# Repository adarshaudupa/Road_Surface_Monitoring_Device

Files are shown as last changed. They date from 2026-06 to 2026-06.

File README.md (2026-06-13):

<div align="center">

<!--
  ╔══════════════════════════════════════════════════════════════╗
  ║  IMAGE 1 — BANNER                                            ║
  ║  File: docs/images/banner.png                                ║
  ║  Suggested size: 1280 × 400 px                               ║
  ║  Use Canva / Figma to make a dark-themed banner with the     ║
  ║  project name, a road icon, and your institution name.       ║
  ╚══════════════════════════════════════════════════════════════╝
-->
Banner

#  Road Condition Monitoring System

**A vehicle-mounted embedded sensing platform that autonomously detects road anomalies,
geo-tags them with real-time GPS, and streams telemetry to a live web dashboard.**

<br>










[]()
[]()

</div>

---

##  Table of Contents

- [Overview](#-overview)
- [Live Dashboard Preview](#-live-dashboard-preview)
- [System Architecture](#-system-architecture)
- [Hardware Platform](#-hardware-platform)
- [Sensor Subsystems](#-sensor-subsystems)
- [Firmware Architecture](#-firmware-architecture)
- [Communication Protocol](#-communication-protocol)
- [Road Event Classification](#-road-event-classification)
- [Web Dashboard & Backend](#-web-dashboard--backend)
- [Repository Structure](#-repository-structure)
- [Getting Started](#-getting-started)
- [Team](#-team)
- [Concepts Demonstrated](#-concepts-demonstrated)
- [Future Improvements](#-future-improvements)
- [Current Status](#-current-status)

---

##  Overview

The **Road Condition Monitoring System** is a complete end-to-end embedded IoT platform that mounts on an RC vehicle and autonomously surveys road surface quality in real time.

The STM32F446RE microcontroller fuses data from an **IMU**, **ultrasonic rangefinder**, and **GPS receiver** to detect and geo-tag road anomalies — potholes and rough patches. Classified events are forwarded over UART to an **ESP32-S3 Wi-Fi gateway**, which uploads them to a **Python backend** for live visualization on a Leaflet.js map dashboard.

<br>

| | Capability |
|:---:|:---|
|  | **Multi-sensor fusion** — IMU shock detection cross-validated with ultrasonic surface profiling |
|  | **GPS geo-tagging** — NMEA GPGGA parsing with interrupt-driven ring-buffer architecture |
|  | **Inter-MCU telemetry** — Structured ASCII packet protocol over STM32 ↔ ESP32 UART link |
|  | **Cloud uplink** — HTTP POST pipeline from ESP32 to Python REST API |
|  | **Live dashboard** — Color-coded map markers with per-event shock & distance metrics |
|  | **Vehicle integration** — 3D-printed sensor mounts on a custom RC chassis |

---

##  Live Dashboard Preview

<!--
  ╔══════════════════════════════════════════════════════════════╗
  ║  IMAGE 2 — DASHBOARD SCREENSHOT                             ║
  ║  File: docs/images/dashboard.png                            ║
  ║  Suggested size: 1280 × 720 px                              ║
  ║  Take a full-page screenshot of the running dashboard with   ║
  ║  some events already plotted on the map.                     ║
  ╚══════════════════════════════════════════════════════════════╝
-->
Dashboard

> Real-time Leaflet.js map showing pothole (🔴) and rough road (🟠) events, with per-event shock magnitude, GPS coordinates, and timestamp.

---

##  System Architecture

<!--
  ╔══════════════════════════════════════════════════════════════╗
  ║  IMAGE 3 — SYSTEM ARCHITECTURE DIAGRAM                      ║
  ║  File: docs/images/architecture.png                         ║
  ║  Suggested size: 1400 × 600 px                              ║
  ║  Use draw.io / Excalidraw to recreate the ASCII diagram      ║
  ║  below as a clean block diagram with icons for each node.    ║
  ╚══════════════════════════════════════════════════════════════╝
-->
Architecture Diagram

```
  ┌──────────────┐  I²C    ┌───────────────────────────────────────────────────┐
  │  LSM6DS3 IMU │───────► │                                                   │
  └──────────────┘         │                                                   │  UART    ┌───────────┐  Wi-Fi   ┌────────────────┐
                           │            STM32F446RE                            │────────► │  ESP32-S3 │─────────►│ Backend Server │
  ┌──────────────┐  TIM5   │                                                   │          └───────────┘          └───────┬────────┘
  │   HC-SR04    │───────► │  • Sensor acquisition & fusion                    │                                         │
  └──────────────┘         │  • Event classification (pothole / rough road)    │                                         ▼
                           │  • GPS stream parsing (NMEA GPGGA)                │                                 ┌────────────────┐
  ┌──────────────┐  UART   │  • Telemetry packet generation                    │                                 │ Web Dashboard  │
  │   NEO-6M GPS │───────► │                                                   │                                 │  (Leaflet.js)  │
  └──────────────┘         └───────────────────────────────────────────────────┘                                 └────────────────┘
```

Data flows from raw sensor readings all the way to a browser-rendered map in under a second.

---

##  Hardware Platform

<!--
  ╔══════════════════════════════════════════════════════════════╗
  ║  IMAGE 4 — HARDWARE / RC CAR PHOTO                           ║
  ║  File: docs/images/hardware.png                              ║
  ║  Suggested size: 1200 × 800 px                               ║
  ║  A well-lit photo of the RC car with components labelled.    ║
  ║  Use Canva or GIMP to add callout labels over the photo.     ║
  ╚══════════════════════════════════════════════════════════════╝
-->
Hardware Platform

### Processing Nodes

| Component | Role |
|---|---|
| **STM32F446RE** | Primary sensing & processing node — sensor drivers, event classification, telemetry generation |
| **ESP32-S3** | Communication gateway — Wi-Fi HTTP uplink + BLE-based RC vehicle control |

### Sensors & Peripherals

| Device | Interface | Function |
|---|---|---|
| **LSM6DS3** | I²C | 6-axis IMU — accelerometer for shock detection |
| **HC-SR04** | TIM5 Input Capture | Ultrasonic rangefinder — road surface profiling |
| **NEO-6M** | UART | GPS receiver — position, altitude & time |
| **TB6612FNG** | GPIO / PWM | Dual motor driver — RC vehicle drive control |

### Communication Interfaces

| Link | Nodes | Protocol |
|---|---|---|
| I²C | STM32 ↔ LSM6DS3 | Register-level IMU configuration & data read |
| UART1 | STM32 ↔ NEO-6M | NMEA 0183 GPS stream (interrupt-driven) |
| UART2 | STM32 ↔ ESP32 | Structured ASCII telemetry packets |
| Wi-Fi | ESP32 ↔ Backend | HTTP POST (JSON telemetry) |
| BLE | Phone ↔ ESP32 | RC vehicle real-time control |

<!--
  ╔══════════════════════════════════════════════════════════════╗
  ║  IMAGE 5 — WIRING / PINOUT DIAGRAM                           ║
  ║  File: docs/images/wiring.png                                ║
  ║  Suggested size: 1200 × 900 px                               ║
  ║  Use Fritzing or draw.io to draw the wiring between the      ║
  ║  STM32, ESP32, sensors, and motor driver.                    ║
  ╚══════════════════════════════════════════════════════════════╝
-->
Wiring Diagram

---

##  Sensor Subsystems

###  LSM6DS3 — IMU Shock Detection

The accelerometer continuously monitors vehicle dynamics. A **low-pass gravity estimation** filter runs every sample to cleanly isolate vertical shock from static gravity:

```
Raw Accelerometer Output (x, y, z)
            │
            ▼  exponential low-pass  (α = 0.1)
    Gravity Vector Estimate  [gx, gy, gz]
            │
            ▼  vector subtraction
    Dynamic Acceleration  [ax, ay, az]
            │
            ▼  dot product with gravity unit vector
    Vertical Shock Magnitude  (g-units)
            │
            ▼  threshold comparison
    Road Event Trigger  ──►  Pothole / Rough Road
```

<!--
  ╔══════════════════════════════════════════════════════════════╗
  ║  IMAGE 6 — IMU SIGNAL WAVEFORM                               ║
  ║  File: docs/images/imu-signal.png                            ║
  ║  Suggested size: 1200 × 500 px                               ║
  ║  Use Arduino Serial Plotter or Matplotlib to plot the raw    ║
  ║  vs filtered IMU signal with a pothole event highlighted.    ║
  ╚══════════════════════════════════════════════════════════════╝
-->
IMU Signal Plot

**Implemented:** I²C init & WHO_AM_I validation · ODR & full-scale configuration · gravity estimation · low-pass filtering · vertical shock extraction · real-time interrupt processing

---

###  HC-SR04 — Ultrasonic Road Surface Measurement

TIM5 hardware input capture measures the echo pulse duration to calculate chassis-to-road distance with microsecond precision:

```
STM32 GPIO Trigger ──► 10 μs pulse
                               │
                               ▼
                        HC-SR04 emits ultrasonic burst
                               │
                               ▼
                         Echo Pin HIGH
                               │  ◄─── TIM5 Capture (rising edge)
                               ▼
                         Echo Pin LOW
                               │  ◄─── TIM5 Capture (falling edge)
                               │
                               ▼
                    Δt  =  t_fall − t_rise
                               │
                               ▼
                    Distance  =  (Δt × 343 m/s) / 2
```

**Implemented:** TIM5 input capture · rising & falling edge detection · hardware-timed pulse width measurement · non-blocking interrupt-driven acquisition

---

###  NEO-6M — GPS Telemetry

The GPS module streams **NMEA 0183** sentences continuously. The firmware implements a **ring-buffer producer–consumer** architecture to parse GPS data without ever blocking the main control loop:

```
UART3 RX Interrupt  ──►  Ring Buffer  (producer — ISR context)
                                │
                                ▼
                       Main Loop polls (consumer)
                                │
                                ▼
                     NMEA Sentence Reconstruction
                                │
                                ▼
                          GPGGA Parser
                                │
                                ▼
              ┌─────────────────┼──────────────────┐
              ▼                 ▼                  ▼
          UTC Time          Lat / Lon           Altitude
         Fix Quality     Satellite Count
```

<!--
  ╔══════════════════════════════════════════════════════════════╗
  ║  IMAGE 7 — GPS MAP TRACK                                     ║
  ║  File: docs/images/gps-track.png                             ║
  ║  Suggested size: 1200 × 700 px                               ║
  ║  Screenshot of the dashboard after a full test run with      ║
  ║  a visible GPS track of the vehicle route plotted on the map ║
  ╚══════════════════════════════════════════════════════════════╝
-->
GPS Track

**Implemented:** UART interrupt handling · circular ring buffer · stream-based NMEA reconstruction · GPGGA sentence parsing · UTC time, lat/lon, altitude, fix quality, satellite count

---

##  Firmware Architecture

The repository ships **two STM32 firmware variants** (HAL-based and bare-metal) alongside the ESP32 gateway sketch.

### `firmware-stm32-hal/` — Primary HAL-based Firmware

```
main.c                 ← System init, sensor loop, event classification, packet dispatch
  ├── LSM6DS3.c / .h   ← I²C IMU driver — init, read, gravity filter, shock extraction
  ├── HC_SR04.c / .h   ← TIM5 input-capture ultrasonic driver
  ├── NEO_6M.c  / .h   ← Interrupt-driven GPS UART + ring buffer + GPGGA parser
  └── ESP32.c   / .h   ← UART telemetry framing & transmission to ESP32
```

### `firmware-stm32-baremetal/` — Register-Level Implementation

```
main.c                   ← Bare-metal system init and application loop
  ├── lsm6ds3.c / .h     ← Direct register-level IMU driver (no HAL)
  ├── hc-sr04.c / .h     ← Register-level TIM5 driver
  ├── NEO_6M.c  / .h     ← Bare-metal UART + ring buffer
  └── esp32_comms.c / .h ← Low-level UART telemetry TX
```

> The bare-metal variant is provided as an educational reference demonstrating the same functionality at the register level, without relying on the STM32 HAL abstraction layer.

### `firmware-esp32/road_surface_monitor.ino` — Wi-Fi Gateway

```
road_surface_monitor.ino
  ├── STM32 UART reception & packet parsing
  ├── Dynamic baseline tracking for ultrasonic depth calculation
  ├── Wi-Fi connection management with status logging
  ├── HTTP POST telemetry upload to backend API
  └── BLE UART service for real-time RC vehicle control
```

---

##  Communication Protocol

The STM32 generates structured **ASCII telemetry packets** over UART. Two event types are defined:

| Event | Packet Format |
|---|---|
| **Rough Road** | `R,<shock_g>,<latitude>,<longitude>,<utc_timestamp>` |
| **Pothole** | `P,<shock_g>,<distance_cm>,<latitude>,<longitude>,<utc_timestamp>` |

**Example packets:**
```
R,1.82,12.971598,77.594562,134502.00
P,2.47,18.30,12.971598,77.594562,134512.00
```

The ESP32 parses these, enriches with `device_id`, and HTTP POSTs to the backend:

```http
POST /api/ingest HTTP/1.1
Host: 10.x.x.x:8000
Content-Type: application/json

{
  "device_id":  "esp32-car-01",
  "event":      "pothole",
  "shock":       2.47,
  "distance":   18.30,
  "lat":        12.971598,
  "lon":        77.594562,
  "timestamp":  "134512.00"
}
```

---

##  Web Dashboard & Backend

<!--
  ╔══════════════════════════════════════════════════════════════╗
  ║  IMAGE 8 — DASHBOARD DETAIL / GIF                            ║
  ║  File: docs/images/dashboard-detail.gif  (or .png)           ║
  ║  Suggested size: 1280 × 720 px                               ║
  ║  Record a short screen capture (GIF via ScreenToGif /        ║
  ║  Kap) showing a new event appearing live on the map.         ║
  ╚══════════════════════════════════════════════════════════════╝
-->
Dashboard Detail

The Python backend (`server.py`) exposes a minimal REST API:

| Endpoint | Method | Description |
|---|---|---|
| `/api/ingest` | `POST` | Receive & store telemetry from ESP32 |
| `/api/events` | `GET` | Retrieve all logged road events |
| `/` | `GET` | Serve the web dashboard |

The frontend (`index.html` + `app.js`) renders all events on an interactive **Leaflet.js** map with color-coded markers and per-event metric cards:

| Marker | Event Type |
|---|---|
| 🔴 **Red** | Pothole — high-severity surface deviation (IMU + ultrasonic confirmed) |
| 🟠 **Orange** | Rough Road — vibration-based surface anomaly (IMU only) |

**Stack:** Python · Leaflet.js · Vanilla JS · CSS Custom Properties · Groq AI integration

---

## 📂 Repository Structure

```
road-condition-monitoring-system/
│
├── firmware-stm32-hal/              ← Primary STM32 firmware (STM32CubeIDE / HAL)
│   ├── Core/
│   │   ├── Src/                     ← main.c, LSM6DS3.c, HC_SR04.c, NEO_6M.c, ESP32.c
│   │   └── Inc/                     ← Header files for all modules
│   └── Drivers/                     ← CMSIS + ST HAL drivers (auto-generated)
│
├── firmware-stm32-baremetal/        ← Register-level reference implementation
│   ├── Core/
│   │   ├── Src/                     ← main.c, lsm6ds3.c, hc-sr04.c, NEO_6M.c, esp32_comms.c
│   │   └── Inc/
│   └── Drivers/
│
├── firmware-esp32/
│   └── road_surface_monitor.ino     ← ESP32 Wi-Fi gateway + BLE RC control
│
├── web-dashboard/
│   ├── server.py                    ← Python backend REST API
│   ├── app.js                       ← Frontend map logic & live event rendering
│   ├── index.html                   ← Dashboard UI shell
│   ├── styles.css                   ← Dark-theme stylesheet
│   └── .env.example                 ← Environment variable template
│
├── model-design/
│   └── Front Leg.stl                ← 3D-printable sensor mount (FDM-ready)
│
└── docs/
    └── images/                      ← ← ← Put all your README images here
        ├── banner.png
        ├── dashboard.png
        ├── dashboard-detail.gif
        ├── architecture.png
        ├── hardware.png
        ├── wiring.png
        ├── imu-signal.png
        └── gps-track.png
```

---

##  Getting Started

### Prerequisites

- [STM32CubeIDE](https://www.st.com/en/development-tools/stm32cubeide.html) — for STM32 firmware
- [Arduino IDE](https://www.arduino.cc/en/software) with [ESP32 board support](https://docs.espressif.com/projects/arduino-esp32/en/latest/installing.html)
- Python 3.9+ — for the backend server
- ST-Link V2/V3 debugger — for flashing the STM32

---

### 1 · Flash the STM32

```bash
# In STM32CubeIDE:
File → Import → General → Existing Projects into Workspace

# Choose one of:
#   firmware-stm32-hal/          ← recommended (HAL-based)
#   firmware-stm32-baremetal/    ← advanced (register-level)

# Build (Ctrl+B) then flash via Run → Debug (ST-Link)
```

---

### 2 · Flash the ESP32

```bash
# Open in Arduino IDE:
firmware-esp32/road_surface_monitor.ino

# Edit the Wi-Fi & server credentials:
const char* WIFI_SSID  = "your_ssid";
const char* WIFI_PASS  = "your_password";
const char* SERVER_URL = "http://<your-server-ip>:8000/api/ingest";

# Board: ESP32S3 Dev Module
# Flash via Arduino IDE → Upload (Ctrl+U)
```

---

### 3 · Run the Backend & Dashboard

```bash
cd web-dashboard

# Copy env template and add your API key
cp .env.example .env
# Edit .env: GROQ_API_KEY=your_key_here

# Install Python dependencies
pip install -r requirements.txt

# Start the server
python server.py

# Dashboard is live at:
# http://localhost:8000
```

---

##  Team

<table>
  <tr>
    <td align="center" width="50%">
      <a href="https://github.com/adarshaudupa">
        <b>Adarsh Udupa</b>
      </a>
      <br><br>
      <b>Firmware Lead & Embedded Integration</b>
      <br><br>
      STM32 system architecture · <code>main.c</code> integration ·
      LSM6DS3 I²C driver · gravity estimation algorithm ·
      vertical shock extraction · HC-SR04 timer input-capture driver ·
      end-to-end subsystem coordination
    </td>
    <td align="center" width="50%">
      <a href="https://github.com/Sumed-Sreedhar">
        <b>Sumed Sreedhar</b>
      </a>
      <br><br>
      <b>GPS Systems & Telemetry Architecture</b>
      <br><br>
      NEO-6M interrupt-driven UART driver · ring buffer architecture ·
      NMEA sentence reconstruction · GPGGA parsing ·
      STM32 ↔ ESP32 packet protocol design · ESP32 firmware ·
      Wi-Fi telemetry pipeline
    </td>
  </tr>
  <tr>
    <td align="center" width="50%">
      <a href="https://github.com/tanmayhutt">
        <b>Tanmay Tiwari</b>
      </a>
      <br><br>
      <b>Backend & IoT Infrastructure</b>
      <br><br>
      Python REST API · database integration · telemetry ingestion pipeline ·
      web dashboard (Leaflet.js) · data visualization ·
      cloud communication architecture · Groq AI integration
    </td>
    <td align="center" width="50%">
      <a href="https://github.com/bandapratham">
        <b>Pratham Banda</b>
      </a>
      <br><br>
      <b>Mechanical Design & Hardware Integration</b>
      <br><br>
      RC vehicle chassis design · AutoCAD modelling ·
      3D-printed sensor mounts · TB6612FNG motor driver integration ·
      power distribution · vehicle wiring & assembly ·
      hardware-level system testing
    </td>
  </tr>
</table>

---

##  Concepts Demonstrated

<details>
<summary><b>Click to expand the full list</b></summary>

<br>

**Embedded Systems**
- Bare-metal register-level peripheral programming
- STM32 HAL abstraction layer usage
- Interrupt-driven firmware architecture
- Timer input capture (TIM5)
- I²C peripheral integration
- UART multi-channel communication
- Non-blocking sensor acquisition

**Signal Processing & Algorithms**
- Low-pass gravity estimation filter
- Dynamic acceleration extraction via vector projection
- Threshold-based event detection
- Ring buffer / circular buffer implementation
- Producer–consumer data flow pattern

**Communication & Networking**
- Inter-MCU UART protocol design
- Structured telemetry packet framing
- NMEA 0183 GPS stream parsing
- Wi-Fi HTTP/REST client (ESP32)
- BLE UART service (ESP32 ↔ mobile)

**Systems Design**
- Distributed embedded processing architecture
- Multi-sensor data fusion fundamentals
- End-to-end embedded-to-cloud data pipeline
- Firmware modularization & driver abstraction
- IoT system integration

</details>

---

##  Future Improvements

| Enhancement | Description |
|---|---|
|  **Coordinate Precision** | GPS decimal-degree conversion & HDOP-based accuracy filtering |
|  **Local Logging** | SD card buffering for offline operation in GPS/Wi-Fi dead zones |
|  **Adaptive Thresholds** | Self-calibrating event detection that learns road baseline per session |
|  **Kalman Filtering** | Optimal sensor fusion for improved vertical shock estimation |
|  **ML Classification** | On-device or edge neural network for road condition categorization |
|  **Cloud Analytics** | Historical data aggregation, heatmaps & trend dashboards |
|  **Mobile Companion App** | Real-time monitoring + RC control in a single mobile app |
|  **V2X Integration** | Vehicle-to-infrastructure telemetry broadcast protocol |
|  **Crowdsourced Mapping** | Multi-device deployment feeding a shared city-wide road quality map |

---

##  Current Status

>  **Functional prototype** — All subsystems integrated and field-tested.

| Subsystem | Status |
|---|---|
| LSM6DS3 IMU shock detection |  Working |
| HC-SR04 ultrasonic ranging |  Working |
| NEO-6M GPS acquisition |  Working |
| STM32 ↔ ESP32 UART telemetry |  Working |
| ESP32 Wi-Fi HTTP upload |  Working |
| Python backend REST API |  Working |
| Leaflet.js map dashboard |  Working |
| BLE RC vehicle control |  Working |
| 3D-printed sensor mount |  Designed & printed |
| Bare-metal reference firmware |  Complete |

---

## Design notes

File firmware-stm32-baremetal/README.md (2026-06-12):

STM32F446RE bare-metal firmware for the road surface monitoring system.

\- Bare-metal drivers for LSM6DS3TR-C IMU (I2C), HC-SR04 (TIM5 input capture + GPIO),

&#x20; and UART links to GPS (NEO-6M) and ESP32-S3.

\- Non blocking sensor fusion loop running at 100 Hz.

\- Built with STM32CubeIDE targeting Nucleo-F446RE.

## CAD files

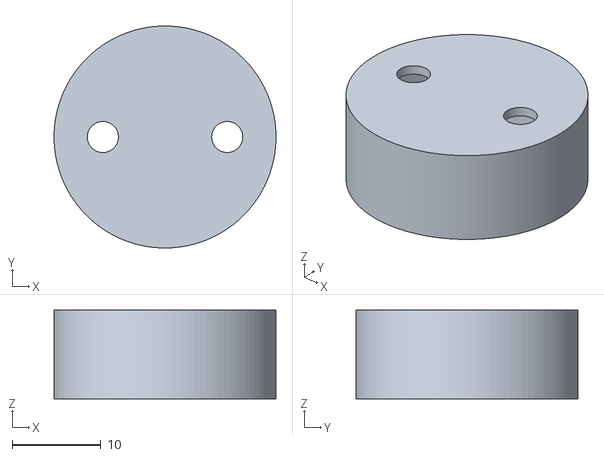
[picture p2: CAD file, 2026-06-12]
model-design/Motor cap.stl
25.0 x 25.0 x 10.0

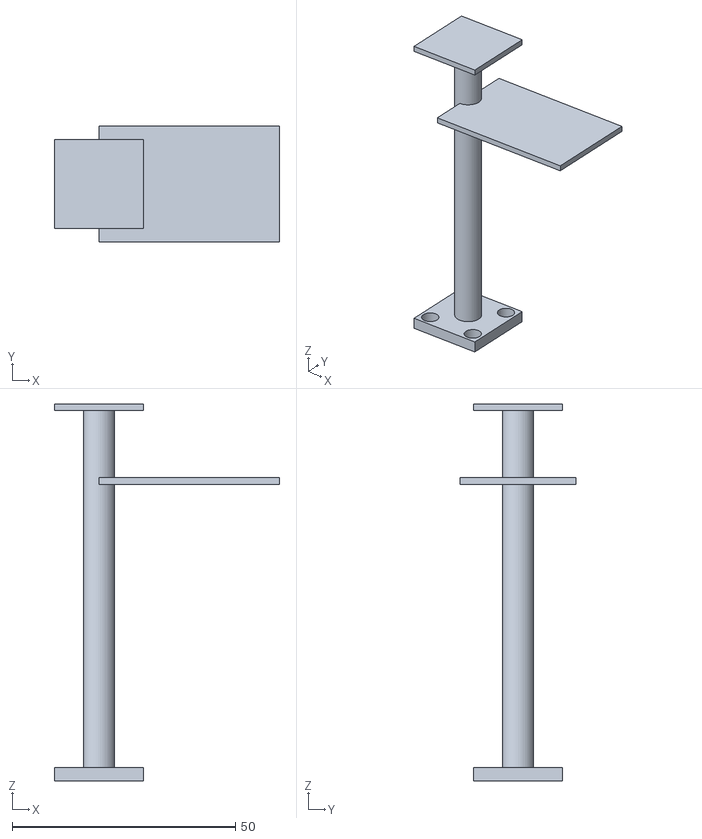
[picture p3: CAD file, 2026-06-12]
model-design/GPS Tower with mount Final Version.stl
50.5 x 26.0 x 84.5

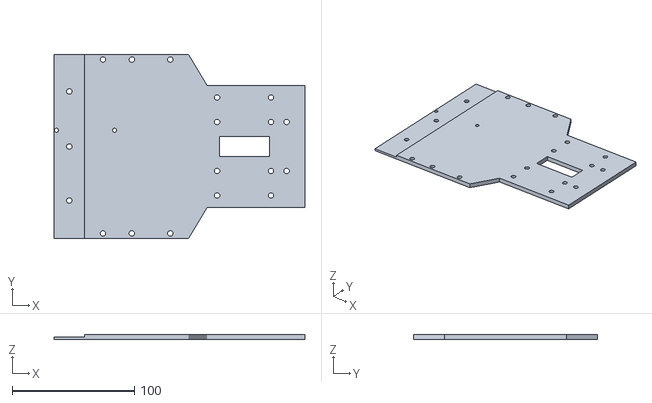
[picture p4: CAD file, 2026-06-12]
model-design/Chassis Base Plate Rear Part Final.stl
205.0 x 150.0 x 4.00

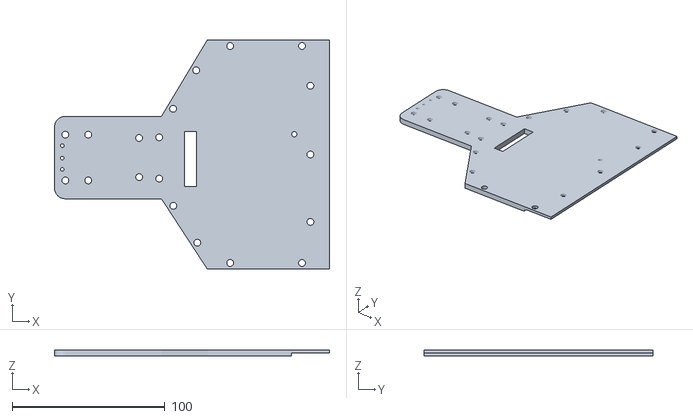
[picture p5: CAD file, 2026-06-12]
model-design/Chassis Base Plate Front Part Final.stl
180.0 x 150.0 x 4.00

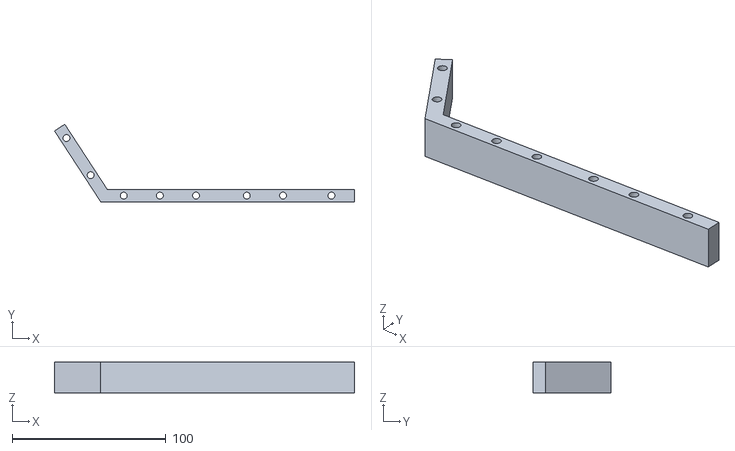
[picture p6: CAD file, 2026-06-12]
model-design/Left Bracket Final Version.stl
195.0 x 50.4 x 20.0

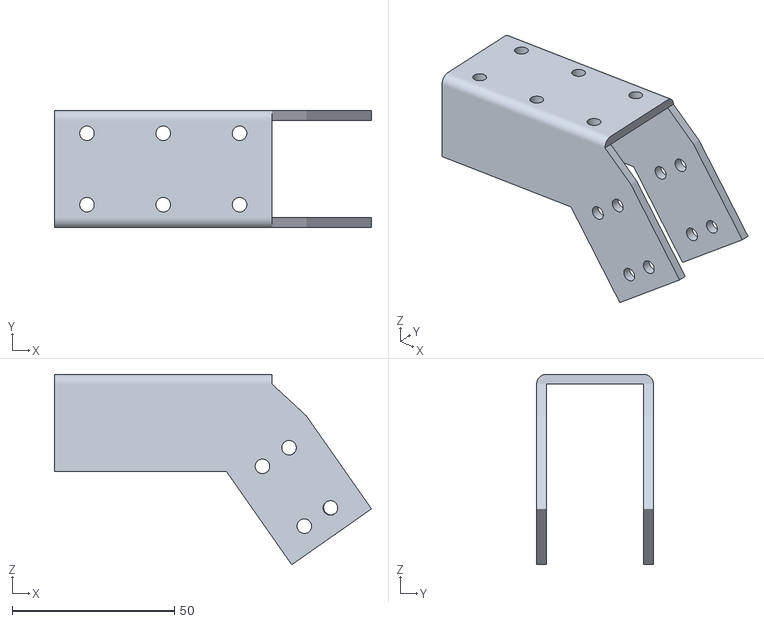
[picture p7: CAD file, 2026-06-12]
model-design/Right Front Leg Holder.stl
97.6 x 36.0 x 58.7

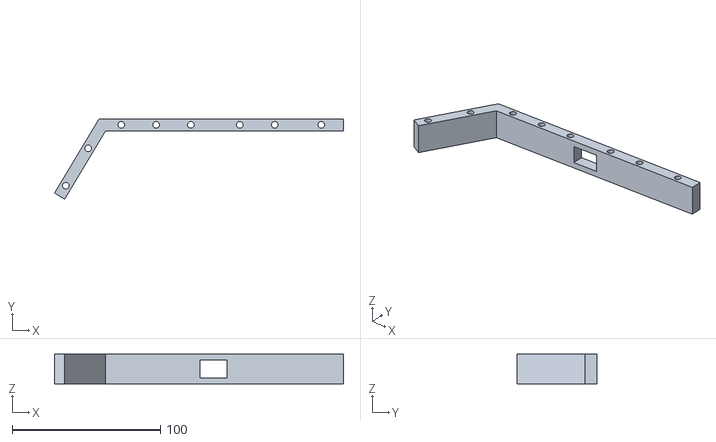
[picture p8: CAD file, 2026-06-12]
model-design/Right Bracket Final Version.stl
195.1 x 54.1 x 20.0

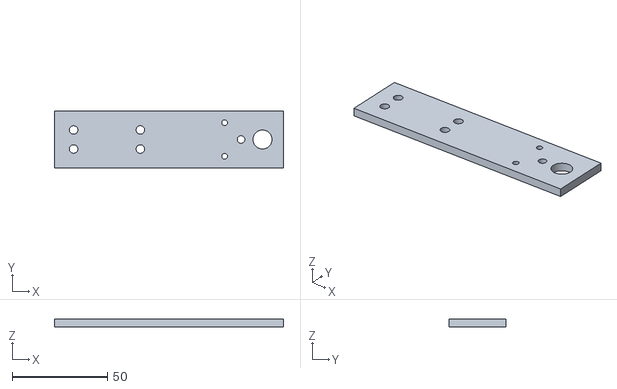
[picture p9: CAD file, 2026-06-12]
model-design/Front Leg.stl
120.0 x 30.0 x 4.00

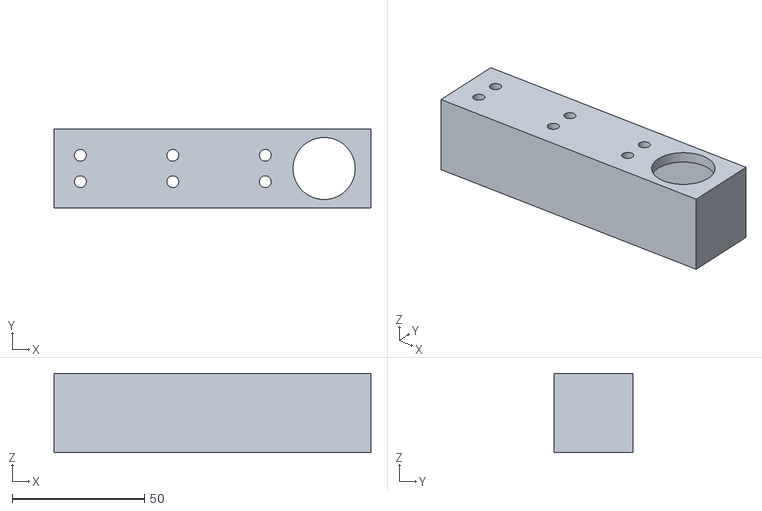
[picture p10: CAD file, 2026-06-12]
model-design/Rear Leg.stl
120.0 x 30.0 x 30.0

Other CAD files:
model-design/Right Rear Leg Holder.stl
model-design/Left Rear Leg Holder.stl

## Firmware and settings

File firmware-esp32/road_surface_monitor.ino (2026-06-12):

#include <Arduino.h>
#include <string>
#include <WiFi.h>
#include <HTTPClient.h>
#include <BLEDevice.h>
#include <BLEServer.h>
#include <BLEUtils.h>
#include <BLE2902.h>

// ── BLE type aliases ────────────────────────────────────────────────────────
#define BLEDEVICE                   BLEDevice
#define BLEServerT                  BLEServer
#define BLEServiceT                 BLEService
#define BLECharacteristicT          BLECharacteristic
#define BLEServerCallbacksT         BLEServerCallbacks
#define BLECharacteristicCallbacksT BLECharacteristicCallbacks
#define BLEAdvertisingT             BLEAdvertising
#define PROP_READ                   BLECharacteristic::PROPERTY_READ
#define PROP_WRITE                  BLECharacteristic::PROPERTY_WRITE
#define PROP_WRITE_NR               BLECharacteristic::PROPERTY_WRITE_NR
#define PROP_NOTIFY                 BLECharacteristic::PROPERTY_NOTIFY
#define ADD_CCCD(c)                 (c)->addDescriptor(new BLE2902())

// ── PIN DEFINITIONS (ESP32-S3 SAFE ZONE) ─────────────────────────────────────
const int PIN_PWMA = 1;
const int PIN_PWMB = 2;
const int PIN_AIN1 = 4;
const int PIN_AIN2 = 5;
const int PIN_BIN1 = 12;
const int PIN_BIN2 = 13;
const int PIN_STBY = 14;

// ── BLE UUIDs ────────────────────────────────────────────────────────────────
static const char* BLE_NAME     = "RC_CAR_BLE";
static const char* SERVICE_UUID = "6E400001-B5A3-F393-E0A9-E50E24DCCA9E";
static const char* RX_UUID      = "6E400002-B5A3-F393-E0A9-E50E24DCCA9E";
static const char* TX_UUID      = "6E400003-B5A3-F393-E0A9-E50E24DCCA9E";

// ── WiFi / telemetry config ─────────────────────────────────────────────────
const char* WIFI_SSID = "Nothing Phone 2a";
const char* WIFI_PASS = "1234567890";
const char* SERVER_URL = "http://10.193.26.79:8000/api/ingest";
const char* DEVICE_ID = "esp32-car-01";

// ── UART from STM32 ──────────────────────────────────────────────────────────
static const int STM32_RX_PIN = 16;
static const int STM32_TX_PIN = 17;

// Legacy packet support. Keep this if older firmware still sends TIME/LAT/LON.
const double GPS_SCALE = 1000000.0;
const float LSM6DS3_LSB_PER_G = 16384.0f;

// Distance baseline for ultrasonic depth/height calculation.
const float DISTANCE_BASELINE_ALPHA = 0.05f;

// ── PWM & Speed settings ─────────────────────────────────────────────────────
const int PWM_FREQ = 20000;
const int PWM_RES  = 8;
const int MAX_SPEED = 255;

// ── State ────────────────────────────────────────────────────────────────────
volatile char lastDir = 'S';
volatile unsigned long lastCmdMs = 0;
volatile bool deviceConnected = false;
volatile bool isAwake = false;

BLECharacteristicT* txChar = nullptr;
HardwareSerial STM32_UART(2);

String uartBuffer;
float distanceBaselineCm = 0.0f;
bool baselineReady = false;
unsigned long lastWiFiAttempt = 0;
unsigned long lastUartIdleLog = 0;
wl_status_t lastWiFiStatus = WL_IDLE_STATUS;
bool wifiStarted = false;

void resetDistanceBaseline() {
  distanceBaselineCm = 0.0f;
  baselineReady = false;
}

float updateBaseline(float distanceCm) {
  if (!baselineReady) {
    distanceBaselineCm = distanceCm;
    baselineReady = true;
    return 0.0f;
  }

  distanceBaselineCm =
      distanceBaselineCm * (1.0f - DISTANCE_BASELINE_ALPHA) +
      distanceCm * DISTANCE_BASELINE_ALPHA;

  return distanceCm - distanceBaselineCm;
}

void logWiFiStatus() {
  wl_status_t status = WiFi.status();
  if (status == lastWiFiStatus) {
    return;
  }

  lastWiFiStatus = status;

  switch (status) {
    case WL_CONNECTED:
      Serial.println("WiFi connected");
      Serial.print("IP: ");
      Serial.println(WiFi.localIP());
      break;
    case WL_NO_SSID_AVAIL:
      Serial.println("WiFi SSID not found");
      break;
    case WL_CONNECT_FAILED:
      Serial.println("WiFi connect failed");
      break;
    case WL_CONNECTION_LOST:
      Serial.println("WiFi connection lost");
      break;
    case WL_DISCONNECTED:
      Serial.println("WiFi disconnected");
      break;
    default:
      Serial.println("WiFi status changed");
      break;
  }
}

void connectWiFi() {
  if (WiFi.status() == WL_CONNECTED) {
    return;
  }

  unsigned long now = millis();
  if (now - lastWiFiAttempt < 5000) {
    return;
  }

  lastWiFiAttempt = now;
  if (!wifiStarted) {
    Serial.println("Connecting to WiFi...");
    wifiStarted = true;
  }
  WiFi.begin(WIFI_SSID, WIFI_PASS);
}

void pwmSetup() {
  ledcAttach(PIN_PWMA, PWM_FREQ, PWM_RES);
  ledcAttach(PIN_PWMB, PWM_FREQ, PWM_RES);
}

void pwmWrite(int pin, int duty) {
  ledcWrite(pin, duty);
}

void setMotor(int in1, int in2, int pwmPin, int speed, int dir) {
  if (dir == 0 || speed <= 0 || !isAwake) {
    digitalWrite(in1, LOW);
    digitalWrite(in2, LOW);
    pwmWrite(pwmPin, 0);
    return;
  }

  digitalWrite(in1, dir > 0 ? HIGH : LOW);
  digitalWrite(in2, dir > 0 ? LOW : HIGH);
  pwmWrite(pwmPin, constrain(speed, 0, MAX_SPEED));
}

void stopAll() {
  setMotor(PIN_AIN1, PIN_AIN2, PIN_PWMA, 0, 0);
  setMotor(PIN_BIN1, PIN_BIN2, PIN_PWMB, 0, 0);
}

void drive(char cmd) {
  if (!isAwake) {
    return;
  }

  switch (cmd) {
    case 'F':
      setMotor(PIN_AIN1, PIN_AIN2, PIN_PWMA, MAX_SPEED, 1);
      setMotor(PIN_BIN1, PIN_BIN2, PIN_PWMB, MAX_SPEED, 1);
      break;
    case 'B':
      setMotor(PIN_AIN1, PIN_AIN2, PIN_PWMA, MAX_SPEED, -1);
      setMotor(PIN_BIN1, PIN_BIN2, PIN_PWMB, MAX_SPEED, -1);
      break;
    case 'L':
      setMotor(PIN_AIN1, PIN_AIN2, PIN_PWMA, MAX_SPEED, -1);
      setMotor(PIN_BIN1, PIN_BIN2, PIN_PWMB, MAX_SPEED, 1);
      break;
    case 'R':
      setMotor(PIN_AIN1, PIN_AIN2, PIN_PWMA, MAX_SPEED, 1);
      setMotor(PIN_BIN1, PIN_BIN2, PIN_PWMB, MAX_SPEED, -1);
      break;
    default:
      stopAll();
      break;
  }
}

void sendStatus(const char* msg) {
  if (txChar && deviceConnected) {
    txChar->setValue((uint8_t*)msg, strlen(msg));
    txChar->notify();
    Serial.print("[TX] ");
    Serial.println(msg);
  }
}

void handleCommand(String raw) {
  raw.trim();
  raw.toUpperCase();
  if (raw.length() == 0) {
    return;
  }

  Serial.print("[RX] ");
  Serial.println(raw);
  char ch = raw[0];

  if (ch == 'W') {
    isAwake = true;
    digitalWrite(PIN_STBY, HIGH);
    sendStatus("SYSTEM:AWAKE");
    return;
  }

  if (ch == 'X') {
    isAwake = false;
    digitalWrite(PIN_STBY, LOW);
    stopAll();
    lastDir = 'S';
    sendStatus("SYSTEM:SLEEP");
    return;
  }

  if (ch == 'C') {
    resetDistanceBaseline();
    sendStatus("SENSOR:CALIBRATED");
    return;
  }

  if (!isAwake) {
    sendStatus("ERR:SLEEPING_SEND_W");
    return;
  }

  if (ch != 'F' && ch != 'B' && ch != 'L' && ch != 'R' && ch != 'S') {
    sendStatus("ERR:UNKNOWN_CMD");
    return;
  }

  lastCmdMs = millis();
  lastDir = ch;
  drive(lastDir);

  char buf[16];
  snprintf(buf, sizeof(buf), "DIR:%c", lastDir);
  sendStatus(buf);
}

class ServerCallbacks : public BLEServerCallbacksT {
public:
  void onConnect(BLEServerT* pServer) override {
    deviceConnected = true;
    Serial.println("[BLE] Connected");
  }

  void onDisconnect(BLEServerT* pServer) override {
    deviceConnected = false;
    lastDir = 'S';
    stopAll();
    Serial.println("[BLE] Disconnected");
    delay(500);
    BLEDEVICE::startAdvertising();
  }
};

class RxCallbacks : public BLECharacteristicCallbacksT {
public:
  void onWrite(BLECharacteristicT* pCharacteristic) override {
    String value = pCharacteristic->getValue();
    if (value.length() > 0) {
      handleCommand(value);
    }
  }
};

int splitCsv(const String& line, String parts[], int maxParts) {
  int count = 0;
  int start = 0;

  while (count < maxParts) {
    int comma = line.indexOf(',', start);
    if (comma == -1) {
      parts[count++] = line.substring(start);
      break;
    }

    parts[count++] = line.substring(start, comma);
    start = comma + 1;
  }

  for (int i = 0; i < count; ++i) {
    parts[i].trim();
  }

  return count;
}

bool parseLegacyTelemetry(const String& line,
                          float& intensityG,
                          float& lat,
                          float& lng,
                          bool& hasUltrasonic,
                          float& ultrasonicDeltaCm) {
  long latRaw = 0;
  long lngRaw = 0;
  long distanceCm = 0;
  long accelZRaw = 0;
  char timeBuffer[16] = {0};

  int matched = sscanf(
      line.c_str(),
      "TIME:%15[^,],LAT:%ld,LON:%ld,DIST:%ld,ACCZ:%ld",
      timeBuffer,
      &latRaw,
      &lngRaw,
      &distanceCm,
      &accelZRaw);

  if (matched != 5) {
    return false;
  }

  lat = static_cast<float>(latRaw / GPS_SCALE);
  lng = static_cast<float>(lngRaw / GPS_SCALE);
  intensityG = fabs(static_cast<float>(accelZRaw)) / LSM6DS3_LSB_PER_G;
  ultrasonicDeltaCm = updateBaseline(static_cast<float>(distanceCm));
  hasUltrasonic = true;
  return true;
}

static const int TELEMETRY_INVALID = 0;
static const int TELEMETRY_NO_EVENT = 1;
static const int TELEMETRY_EVENT = 2;

int parseCsvTelemetry(const String& line,
                      String& eventTypeName,
                      float& intensityG,
                      float& lat,
                      float& lng,
                      bool& hasUltrasonic,
                      float& ultrasonicDeltaCm) {
  String parts[8];
  int count = splitCsv(line, parts, 8);
  if (count < 2) {
    return TELEMETRY_INVALID;
  }

  String kind = parts[0];
  kind.toUpperCase();

  if (kind == "D") {
    float distanceCm = parts[1].toFloat();
    updateBaseline(distanceCm);
    return TELEMETRY_NO_EVENT;
  }

  if (kind != "P" && kind != "R" && kind != "B") {
    return TELEMETRY_INVALID;
  }

  float shockValue = parts[1].toFloat();
  intensityG = fabs(shockValue) / LSM6DS3_LSB_PER_G;

  if (count >= 6) {
    float distanceCm = parts[2].toFloat();
    lat = parts[3].toFloat();
    lng = parts[4].toFloat();
    ultrasonicDeltaCm = updateBaseline(distanceCm);
    hasUltrasonic = true;
  } else if (count >= 5) {
    lat = parts[2].toFloat();
    lng = parts[3].toFloat();
  } else {
    return TELEMETRY_INVALID;
  }

  if (kind == "P") {
    eventTypeName = "pothole";
  } else if (kind == "B") {
    eventTypeName = "speed_bump";
  } else {
    eventTypeName = "rough_patch";
  }

  return TELEMETRY_EVENT;
}

// ── NEW: Added rawLine parameter to push raw UART to the backend
void sendTelemetry(const String& eventTypeName,
                   float lat,
                   float lng,
                   float intensityG,
                   bool hasUltrasonic,
                   float ultrasonicDeltaCm,
                   const String& rawLine) {
  if (WiFi.status() != WL_CONNECTED) {
    Serial.println("[HTTP] WiFi not connected");
    return;
  }

  WiFiClient wifiClient;
  HTTPClient http;
  if (!http.begin(wifiClient, SERVER_URL)) {
    Serial.println("[HTTP] begin failed");
    return;
  }

  http.setTimeout(3000);
  http.addHeader("Content-Type", "application/json");

  String payload = "{";
  if (eventTypeName.length() > 0) {
    payload += "\"event_type\":\"";
    payload += eventTypeName;
    payload += "\",";
  }

  payload += "\"device_id\":\"";
  payload += DEVICE_ID;
  payload += "\",";
  payload += "\"lat\":" + String(lat, 6) + ",";
  payload += "\"lng\":" + String(lng, 6) + ",";
  payload += "\"accel_peak_g\":" + String(intensityG, 2);

  if (hasUltrasonic) {
    payload += ",\"ultrasonic_delta_cm\":" + String(ultrasonicDeltaCm, 2);
  }

  // --- ADD THE RAW UART DATA TO THE JSON PAYLOAD ---
  payload += ",\"raw_data\":\"" + rawLine + "\"";

  payload += "}";

  Serial.print("[HTTP] Sending payload: ");
  Serial.println(payload);

  int status = http.POST(payload);
  String response = http.getString();
  http.end();

  Serial.print("[HTTP] status: ");
  Serial.println(status);
  Serial.println(response);
}

void handleTelemetryLine(String line) {
  line.trim();
  if (line.length() == 0) {
    return;
  }

  Serial.print("[UART] ");
  Serial.println(line);

  float intensityG = 0.0f;
  float lat = 0.0f;
  float lng = 0.0f;
  bool hasUltrasonic = false;
  float ultrasonicDeltaCm = 0.0f;
  String eventTypeName;

  if (line.startsWith("TIME:")) {
    if (parseLegacyTelemetry(line, intensityG, lat, lng, hasUltrasonic, ultrasonicDeltaCm)) {
      // Pass the raw 'line' into sendTelemetry
      sendTelemetry(eventTypeName, lat, lng, intensityG, hasUltrasonic, ultrasonicDeltaCm, line);
    } else {
      Serial.println("[UART] Invalid legacy packet");
    }
    return;
  }

  int result = parseCsvTelemetry(
      line,
      eventTypeName,
      intensityG,
      lat,
      lng,
      hasUltrasonic,
      ultrasonicDeltaCm);

  if (result == TELEMETRY_EVENT) {
    // Pass the raw 'line' into sendTelemetry
    sendTelemetry(eventTypeName, lat, lng, intensityG, hasUltrasonic, ultrasonicDeltaCm, line);
  } else if (result == TELEMETRY_INVALID) {
    Serial.println("[UART] Invalid packet");
  }
}

void pollTelemetrySerial() {
  while (STM32_UART.available()) {
    char c = static_cast<char>(STM32_UART.read());

    if (c == '\r') {
      continue;
    }

    if (c == '\n') {
      String line = uartBuffer;
      uartBuffer = "";
      handleTelemetryLine(line);
      continue;
    }

    if (uartBuffer.length() < 180) {
      uartBuffer += c;
    } else {
      uartBuffer = "";
      Serial.println("[UART] Buffer overflow");
    }
  }
}

void setup() {
  Serial.begin(115200);
  delay(1000);

  pinMode(PIN_STBY, OUTPUT);
  pinMode(PIN_AIN1, OUTPUT);
  pinMode(PIN_AIN2, OUTPUT);
  pinMode(PIN_BIN1, OUTPUT);
  pinMode(PIN_BIN2, OUTPUT);

  pwmSetup();

  isAwake = false;
  digitalWrite(PIN_STBY, LOW);
  stopAll();

  WiFi.mode(WIFI_STA);
  WiFi.setSleep(false);

  STM32_UART.begin(115200, SERIAL_8N1, STM32_RX_PIN, STM32_TX_PIN);

  BLEDEVICE::init(BLE_NAME);
  BLEServerT* server = BLEDEVICE::createServer();
  server->setCallbacks(new ServerCallbacks());

  BLEServiceT* service = server->createService(SERVICE_UUID);

  BLECharacteristicT* rxChar = service->createCharacteristic(RX_UUID, PROP_WRITE | PROP_WRITE_NR);
  rxChar->setCallbacks(new RxCallbacks());

  txChar = service->createCharacteristic(TX_UUID, PROP_READ | PROP_NOTIFY);
  ADD_CCCD(txChar);

  service->start();
  BLEDEVICE::getAdvertising()->addServiceUUID(SERVICE_UUID);
  BLEDEVICE::startAdvertising();

  Serial.println("[BOOT] Ready. Send 'W' to start the car, 'C' to calibrate the ultrasonic baseline.");
}

void loop() {
  connectWiFi();
  logWiFiStatus();
  pollTelemetrySerial();

  if (STM32_UART.available() == 0 && uartBuffer.length() == 0) {
    unsigned long now = millis();
    if (now - lastUartIdleLog > 5000) {
      Serial.println("Waiting for STM32 data...");
      lastUartIdleLog = now;
    }
  }
}

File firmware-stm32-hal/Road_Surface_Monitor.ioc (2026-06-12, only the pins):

Mcu.UserName=STM32F446RETx
PA0-WKUP.GPIO_Label=ECHO
PA0-WKUP.Signal=S_TIM5_CH1
PA10.Signal=USART1_RX
PA13.Signal=SYS_JTMS-SWDIO
PA14.GPIO_Label=TCK
PA14.Signal=SYS_JTCK-SWCLK
PA2.Signal=USART2_TX
PA3.Signal=USART2_RX
PA6.GPIO_Label=TRIG
PA6.Signal=GPIO_Output
PA9.Signal=USART1_TX
PB10.Signal=USART3_TX
PB3.GPIO_Label=SWO
PB3.Signal=SYS_JTDO-SWO
PB8.Signal=I2C1_SCL
PB9.Signal=I2C1_SDA
PC14-OSC32_IN.Signal=RCC_OSC32_IN
PC15-OSC32_OUT.Signal=RCC_OSC32_OUT
PC5.Signal=USART3_RX
PH0-OSC_IN.Signal=RCC_OSC_IN
PH1-OSC_OUT.Signal=RCC_OSC_OUT

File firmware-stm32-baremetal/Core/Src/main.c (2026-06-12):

#include "stm32f4xx.h"
#include "uart2.h"
#include "uart3.h"
#include "NEO_6M.h"
#include "tim5.h"
#include "i2c1.h"
#include "lsm6ds3.h"
#include "hc-sr04.h"
#include "esp32_comms.h"
#include <string.h>

#define SHOCK_DT_US         10000     // 100Hz sample
#define SHOCK_THRESH        3000      // LSM6DS3 shock threshold for pothole
#define EVENT_COOLDOWN_US  300000     // 300ms

static GPS_Data_t gps_data;

// Pothole event state
static uint32_t last_shock_us   = 0;
static uint32_t last_event_us   = 0;
static uint8_t  send_pending    = 0;  // 1 if need to send depth after US read

// Holds last event for ESP32 packet
static ESP32_Packet_t pkt;

// ──────────────────────────────────────────────────────────────────────────────
int main(void)
{
    // --- Clocks ---
    RCC->CR |= (1 << 0); while (!(RCC->CR & (1 << 1)));     // HSI on
    RCC->CFGR &= ~(3 << 0);  while ((RCC->CFGR & (3 << 2))); // SYSCLK = HSI

    // --- Peripheral init ---
    UART2_Init();
    UART3_Init();
    GPS_Init();           // wires up UART1/ISR/buffer
    TIM5_Init();          // for micros/hc-sr04
    I2C1_Init();
    HCSR04_Init();
    LSM6DS3_Init();

    UART2_SendString("==== POTHOLE DETECTION SYSTEM ====\r\n");
    LSM6DS3_WHOAMI();
    imu_settle_gravity(200, 5); // 1s at 5ms/sample

    // --- Main loop ---
    UART2_SendString("Main Loop Start\r\n");
    while (1)
        {
            uint32_t now = TIM5_GetMicros();
            GPS_Process();

            // --- 1. IMU Polling (100Hz) ---
            if ((uint32_t)(now - last_shock_us) >= SHOCK_DT_US)
            {
                last_shock_us = now;
                int16_t shock = imu_vertical_shock();
                int16_t shock_abs = (shock < 0) ? -shock : shock;

                // Make this threshold lower (e.g., 500) if you don't see events
                uint8_t road_flag = (shock_abs > 500) ? 1 : 0;

                if (road_flag == 1 && (uint32_t)(now - last_event_us) >= EVENT_COOLDOWN_US)
                {
                    last_event_us = now;
                    send_pending = 1;

                    GPS_GetDataCopy(&gps_data);
                    memset(&pkt, 0, sizeof(pkt));
                    pkt.timestamp_us = now;
                    pkt.road_flag    = 1;
                    pkt.shock_lsb    = shock;
                    pkt.dist_cm      = 0;

                    // Copy GPS data
                    strncpy(pkt.lat_raw, gps_data.latitude_raw, sizeof(pkt.lat_raw) - 1);
                    pkt.lat_dir      = gps_data.latitude_direction;
                    strncpy(pkt.lon_raw, gps_data.longitude_raw, sizeof(pkt.lon_raw) - 1);
                    pkt.lon_dir      = gps_data.longitude_direction;
                    pkt.fix_quality  = gps_data.fix_quality;
                    pkt.satellites   = gps_data.satellites;

                    UART2_SendString("*** POTHOLE EVENT DETECTED ***\r\n");
                    HCSR04_Start();
                }
            }

            // --- 2. Asynchronous Distance Check ---
            // This MUST be here to finish the cycle and send the packet
            if (send_pending && HCSR04_IsDone())
            {
                pkt.dist_cm = HCSR04_GetLastCm();
                ESP32_SendPacket(&pkt);

                uart_print_uint("EVENT SENT, DISTANCE_CM = ", pkt.dist_cm);
                send_pending = 0;
            }
        } // End while
    } // End main

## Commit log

2026-06-12 final arduino code with bluetooth connectivity, wifiand uart rx
2026-06-12 repo setup
    [Chassis Base Plate Front Part Final.stl, Chassis Base Plate Rear Part Final.stl, Front Leg.stl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]
2026-06-12 Add STM32 bare-metal firmware directory and initial README
2026-06-12 Add STM32F446RE bare-metal sensor fusion firmware
